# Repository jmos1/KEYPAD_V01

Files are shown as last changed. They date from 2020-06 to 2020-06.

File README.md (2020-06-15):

# KEYPAD_V01
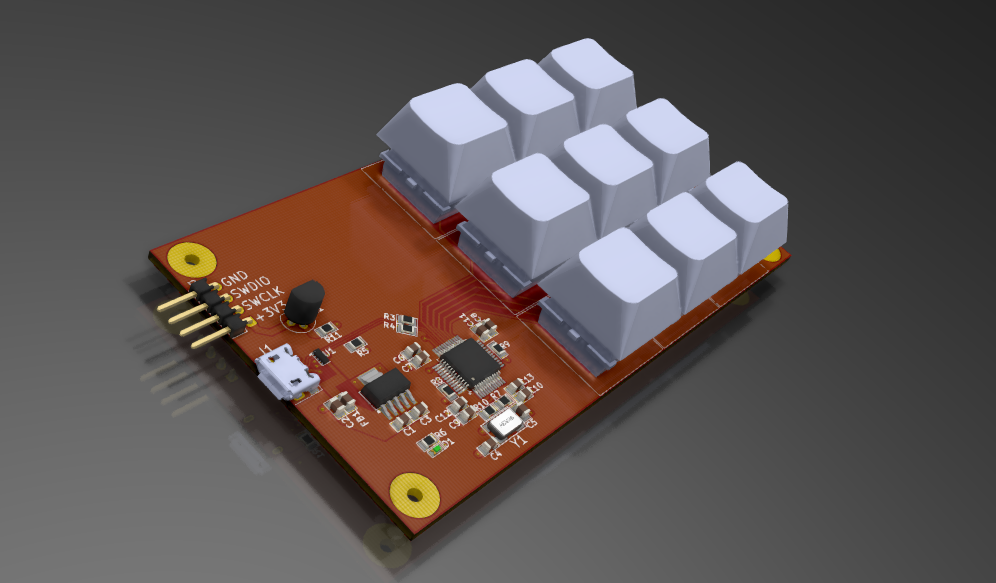
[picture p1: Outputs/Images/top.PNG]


### Summary: ###
  This is a 3x3 keypad designed around the budget STMF103 Cortex-M3 series of microcontrollers. 
  It interfaces to the PC with a USB micro B connector and can be programmed through the SWD interface adjacent to it.

  The BOM, schematic PDF, and gerber files are all accessible in the _'Outputs/'_ folder. 
  Other project files are not included because they add clutter and can be generated from the project itself in KiCad.
  Thanks.
  
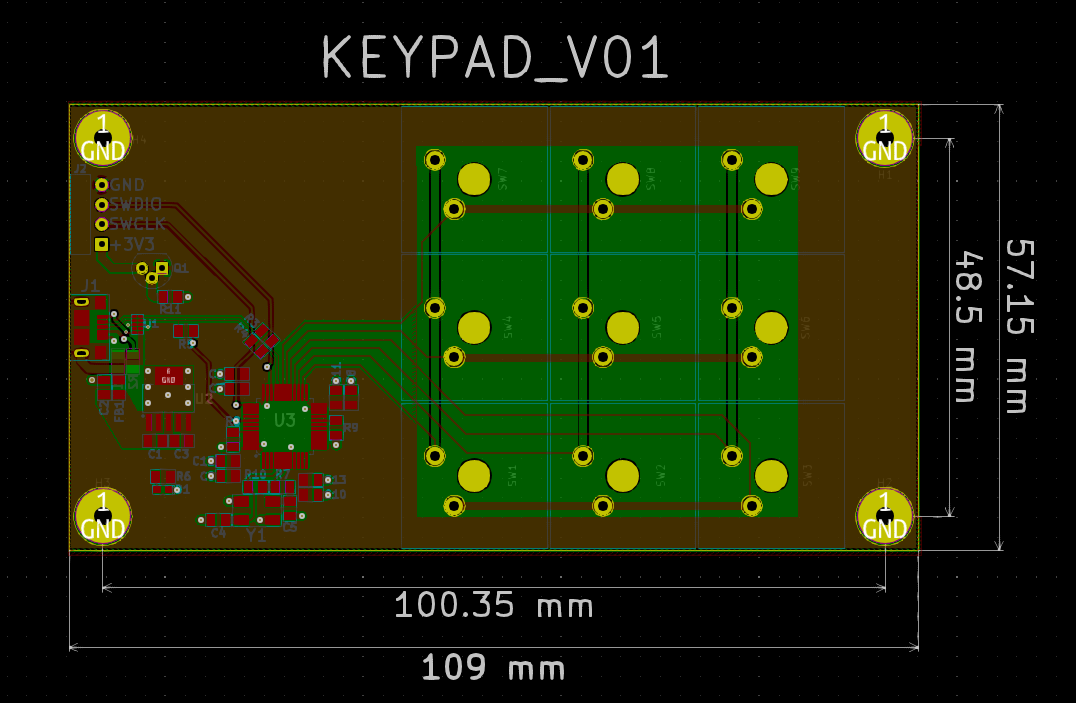
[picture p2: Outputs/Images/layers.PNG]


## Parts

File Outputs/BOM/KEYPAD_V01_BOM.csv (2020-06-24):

Comment | MPN | Manufacturer | Part Number | Supplier | Quantity
1u,25V | CGA4J3X7R1E105K125AB | TDK | 445-5687-1-ND | Digikey | 5
10u,16V | CGA4J1X5R1C106M125AC | TDK | 445-12654-1-ND | Digikey | 2
18p,50V | C0805C180J5GACTU | KEMET | 399-1112-1-ND | Digikey | 2
100n,50V | C2012X7R1H104K085AA | TDK | 445-7534-1-ND | Digikey | 4
GRN | LG L29K-F2J1-24-Z | OSRAM | 475-3118-1-ND | Digikey | 1
MPZ2012S601AT000 | MPZ2012S601AT000 | TDK | 445-2206-1-ND | Digikey | 1
10118193-0001LF | 10118193-0001LF | Amphenol | 609-4616-1-ND | Digikey | 1
HDR_MALE_RA_2.54MM_1X4 | M20-9750446 | Harwin | 952-1965-ND | Digikey | 1
1MR | RC0805FR-071ML | Yageo | 311-1.00MCRCT-ND | Digikey | 1
22R | AC0805FR-0722RL | Yageo | YAG3713CT-ND | Digikey | 2
1K5R | CRG0805F1K5 | TE Connectivity | A106057CT-ND | Digikey | 1
560R | RC0805FR-07560RL | Yageo | 311-560CRCT-ND | Digikey | 2
0R | RC0805JR-070RL | Yageo | 311-0.0ARCT-ND | Digikey | 3
10KR | RC0805FR-0710KL | Yageo | 311-10.0KCRCT-ND | Digikey | 2
Cherry_MX | MX1A-11NN | Cherry Americas | CH162-ND | Digikey | 9
PUSB3FR4Z | PUSB3FR4Z | Nexperia USA | 1727-2026-1-ND | Digikey | 1
TL1963A-33DCQT | TL1963A-33DCQT | Texas Instruments | 296-32342-1-ND | Digikey | 1
STM32F103C8T6TR | STM32F103C8T6TR | ST | 497-17666-1-ND | Digikey | 1
8MHz | ABM3B-8.000MHZ-10-D-1-G-T | Abracon LLC | 535-13456-1-ND | DigiKey | 1
BC32725TA | BC32725TA | ON Semiconductor | BC32725TACT-ND | DigiKey | 1

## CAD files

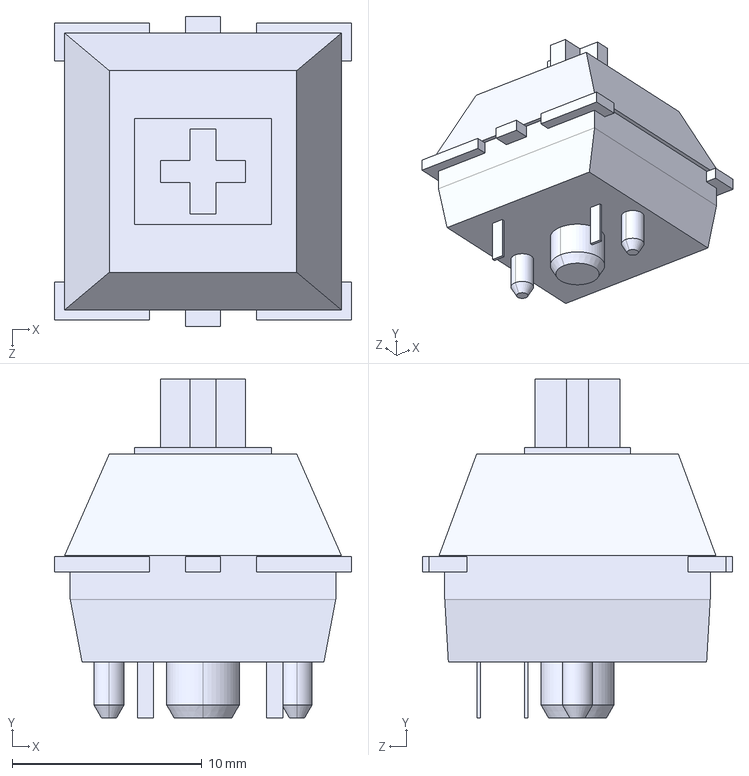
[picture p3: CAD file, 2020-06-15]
3D Models/STEP/cherry mx housing.step
15.6 x 17.9 x 16.3 mm

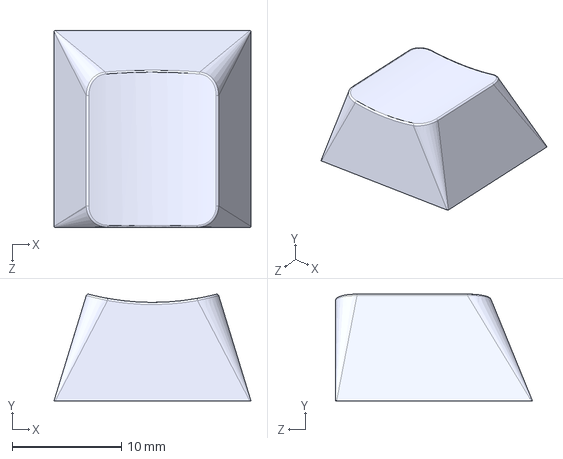
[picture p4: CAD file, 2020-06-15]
3D Models/STEP/cherry_mx_r4_keycap.step
18.0 x 9.76 x 18.0 mm

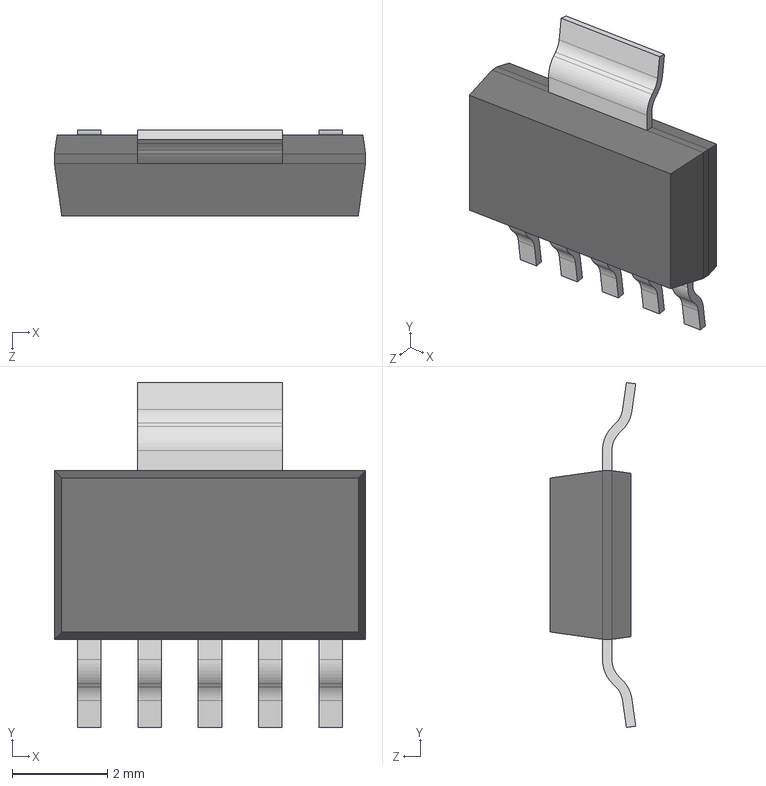
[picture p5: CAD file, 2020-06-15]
3D Models/STEP/SOT-223-6.step
6.55 x 7.26 x 1.80 mm

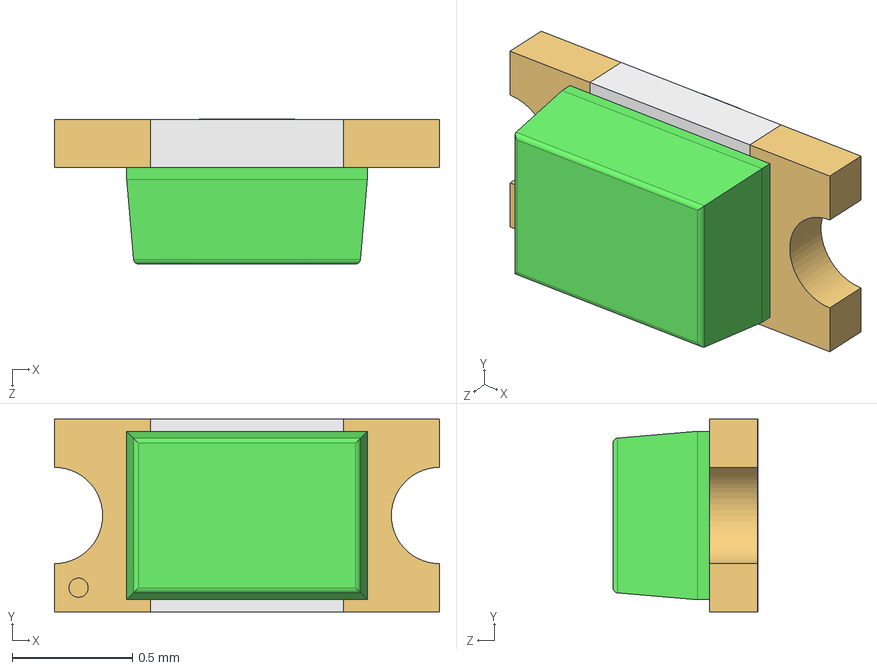
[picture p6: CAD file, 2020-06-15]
3D Models/STEP/LED_0603_GRN.STEP
1.60 x 0.8 x 0.602 mm

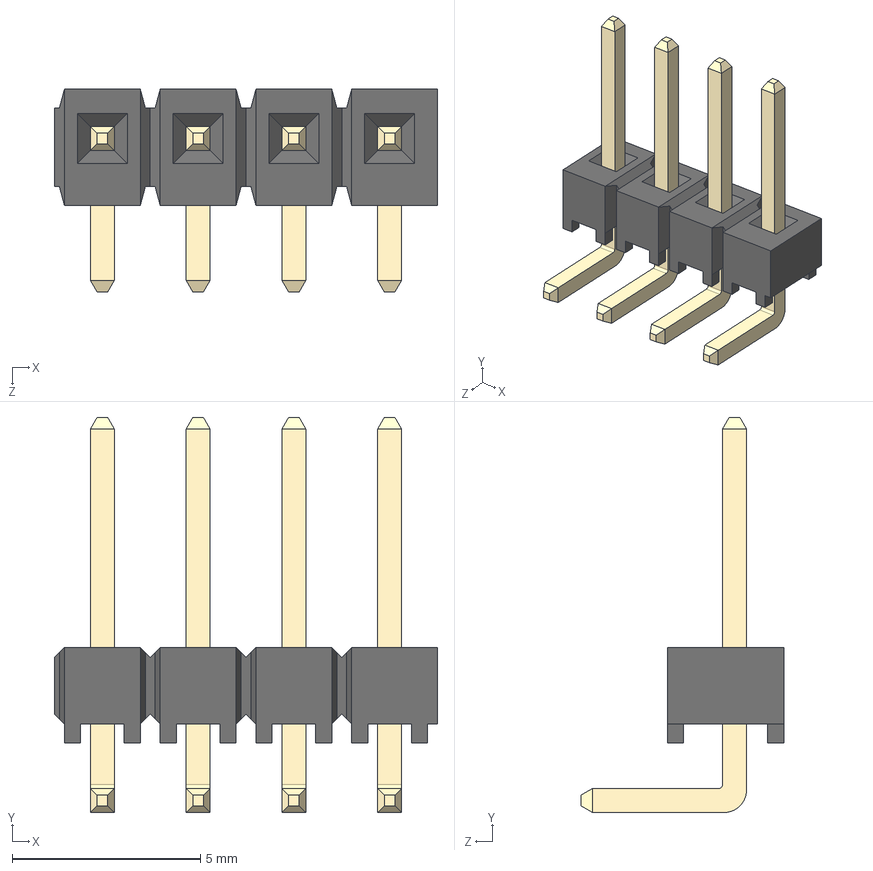
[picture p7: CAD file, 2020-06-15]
3D Models/STEP/Header RightAngle 2_54mm Pitch.step
10.2 x 10.5 x 5.38 mm

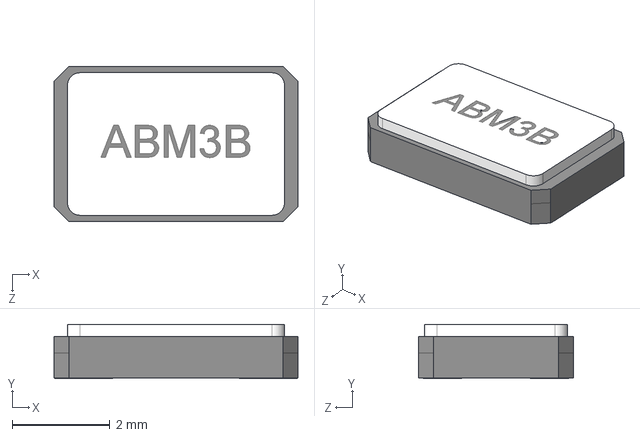
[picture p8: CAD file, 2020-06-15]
3D Models/STEP/ABM3B.STEP
5.00 x 1.11 x 3.18 mm

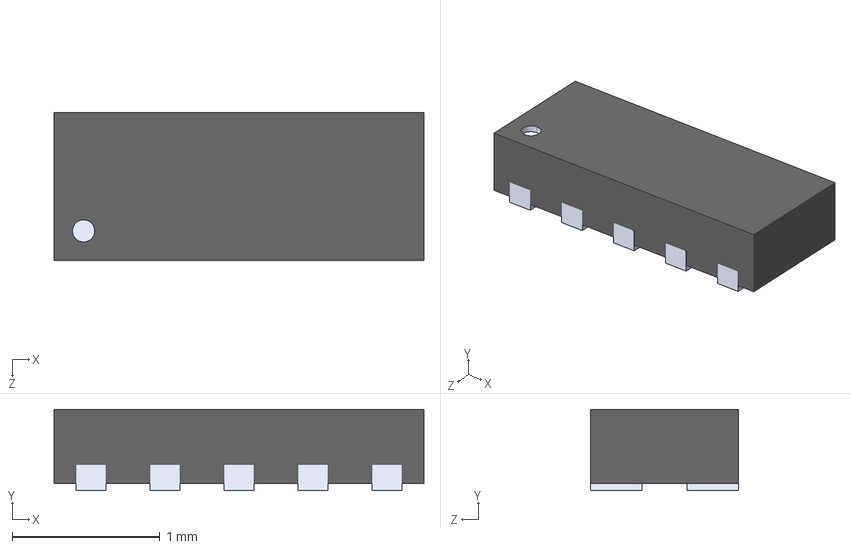
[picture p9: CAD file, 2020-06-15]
3D Models/STEP/DFN2510.step
2.50 x 0.55 x 1.00 mm

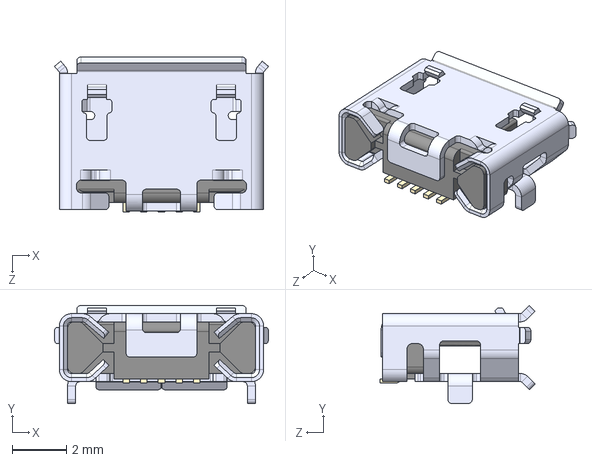
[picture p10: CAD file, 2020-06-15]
3D Models/STEP/10118193-0001LF_USB_Micro.STEP
7.86 x 3.60 x 5.71 mm

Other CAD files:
3D Models/STEP/DCQ6.step

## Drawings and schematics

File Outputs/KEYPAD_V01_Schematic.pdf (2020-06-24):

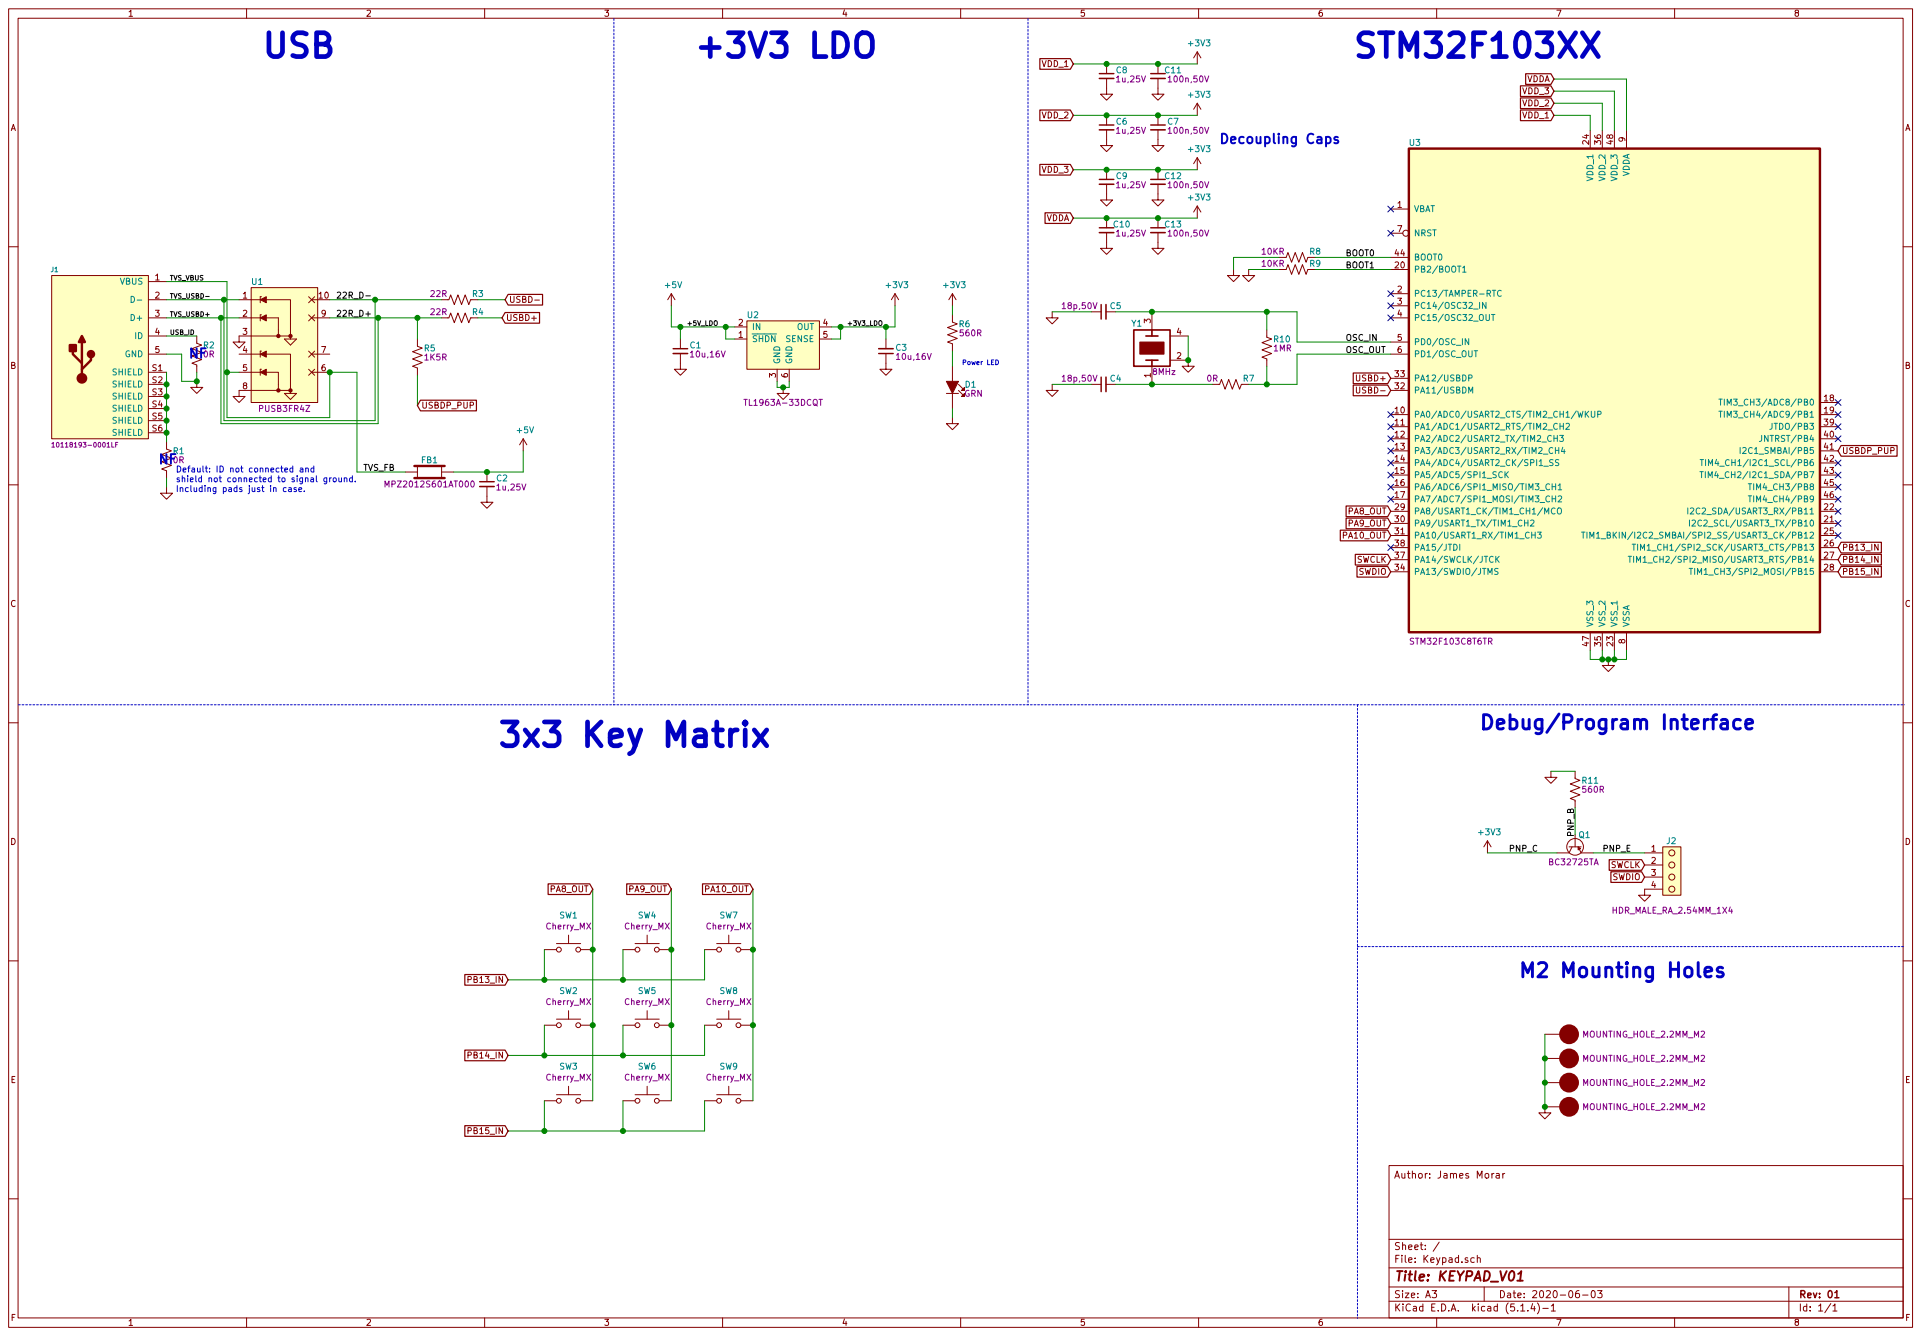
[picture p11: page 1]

Power LED Default: ID not connected and shield not connected to signal ground.

Including pads just in case.

File: Keypad.sch Sheet: / Author: James Morar

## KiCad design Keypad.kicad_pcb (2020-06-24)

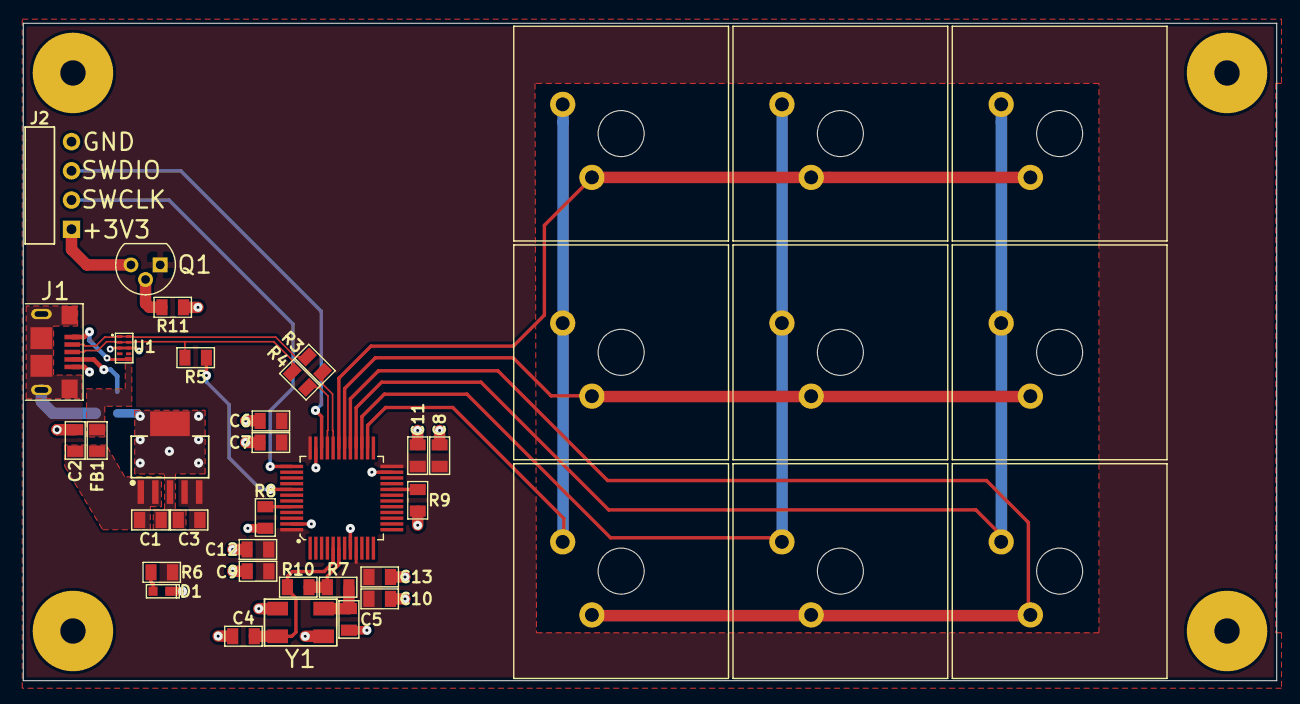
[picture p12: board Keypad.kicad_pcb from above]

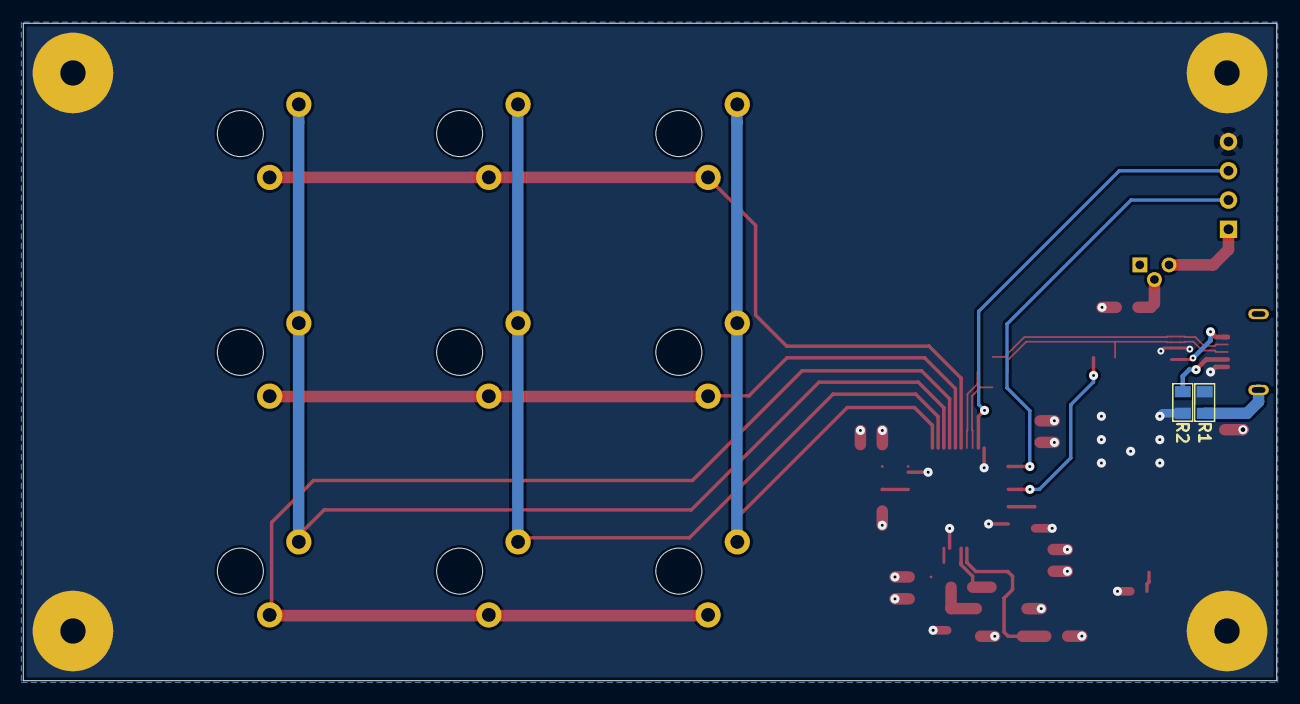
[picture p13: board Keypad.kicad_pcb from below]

Board: 2 copper layers, 109.0 x 57.2 mm, 46 parts (2 on the bottom side), 27 nets.

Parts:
C1, C3: CGA4J1X5R1C106M125AC; C0805
C2, C6, C8, C9, C10: CGA4J3X7R1E105K125AB; C0805
C4, C5: C0805C100J3GAC7800; C0805
C7, C11, C12, C13: C2012X7R1H104K085AA; C0805
D1: L29K-F2J1-24-Z; LG L29K-F2J1-24-Z
FB1: MPZ2012S601AT000; C0805
H1, H2, H3, H4: MOUNTING_HOLE_2.2MM_M2; MountingHole_2.2MM_M2_PAD
J1: 10118193-0001LF; FCI_10118193-0001LF
J2: M20-9750446; HDR_MALE_RA_2.54MM_1X4
Q1: BC32725TA; TO-92
R1, R2, R7: RC0805JR-070RL; R0805
R3, R4: AC0805FR-0722RL; R0805
R5: CRG0805F1K5; R0805
R6, R11: RC0805FR-07560RL; R0805
R8, R9: RC0805FR-0710KL; R0805
R10: RC0805FR-071ML; R0805
SW1, SW2, SW3, SW4, SW5, SW6, SW7, SW8, SW9: MX1A-11NN; SW_CherryMX_1U
U1: PUSB3FR4Z
U2: TL1963A-33DCQT
U3: STM32F103C8T6TR; LQFP-48_STM32F103
Y1: ABM3B-8.000MHZ-10-D-1-G-T; NX8045GB-8.000000MHZ

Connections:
+5V: C1.1, C2.1, FB1.2, U2.1, U2.2
/22R_D+: J1.3, R4.1, R5.1, U1.2, U1.9
/22R_D-: J1.2, R3.1, U1.1, U1.10
/BOOT0: R8.2, U3.44
/BOOT1: R9.2, U3.20
/OSC_IN: C4.2, R10.1, U3.5, Y1.3
/OSC_OUT: R7.2, R10.2, U3.6
/PNP_B: Q1.2, R11.2
/PNP_E: J2.1, Q1.3
/TVS_FB: FB1.1, J1.1, U1.5, U1.6
/USB_ID: J1.4, R2.1
GND: C1.2, C2.2, C3.1, C4.1, C5.1, C6.2, C7.2, C8.2, C9.2, C10.2, C11.2, C12.2, C13.2, D1.2, H1.1, H2.1, H3.1, H4.1, J1.5, J2.4, R1.2, R2.2, R8.1, R9.1, R11.1, U1.3, U1.8, U2.3, U2.6, U3.8, U3.23, U3.35, U3.47, Y1.2, Y1.4
unnamed: C5.2, R7.1, Y1.1
unnamed: D1.1, R6.2
unnamed: J1.S1, J1.S2, J1.S3, J1.S4, J1.S5, J1.S6, R1.1
PA8_OUT: SW1.2, SW2.2, SW3.2, U3.29
PA9_OUT: SW4.2, SW5.2, SW6.2, U3.30
PA10_OUT: SW7.2, SW8.2, SW9.2, U3.31
PB13_IN: SW1.1, SW4.1, SW7.1, U3.26
PB14_IN: SW2.1, SW5.1, SW8.1, U3.27
PB15_IN: SW3.1, SW6.1, SW9.1, U3.28
SWCLK: J2.2, U3.37
SWDIO: J2.3, U3.34
USBD+: R4.2, U3.33
USBD-: R3.2, U3.32
USBDP_PUP: R5.2, U3.41
VDDA: C3.2, C6.1, C7.1, C8.1, C9.1, C10.1, C11.1, C12.1, C13.1, Q1.1, R6.1, U2.4, U2.5, U3.9, U3.24, U3.36, U3.48

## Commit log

2020-06-15 Initial big push
    [10118193-0001LF_USB_Micro.STEP, ABM3B.STEP, DCQ6.step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]
2020-06-15 Modified BOM
    [KEYPAD_V01_BOM.csv]
2020-06-15 Minor measurement fixes
    [Keypad.kicad_pcb]
2020-06-16 Modifications to schematic
    [Keypad.kicad_pcb, Keypad.sch]
2020-06-24 Upadated schematic
    [KEYPAD_V01_BOM.csv, Keypad.kicad_pcb, Keypad.sch]
